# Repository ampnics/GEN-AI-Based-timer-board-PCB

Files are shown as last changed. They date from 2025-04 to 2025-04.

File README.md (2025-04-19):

Gen-AI-Based Timer Board using KiCad and DeepSeek
This project demonstrates the design of a timer control board created using traditional EDA tools supported by generative AI guidance. The goal was to explore how AI can assist in real-world hardware development, from concept to PCB.

Overview
This timer board is designed for applications such as:

Delay-based relay switching

Countdown-based automation

General purpose timing control in embedded systems

It features an ESP-based controller, a relay driver circuit, an OLED display for user feedback, and input buttons for setting time values.

AI Collaboration using DeepSeek
Throughout the project, DeepSeek AI was used to accelerate and refine different stages of the hardware design process:

Block Diagram: AI-generated block-level architecture based on system description.

Schematic Design: Assisted in part selection, logic validation, and drawing guidance.

Design Review: Suggested improvements for schematic correctness and layout optimization.

PCB Layout: Provided tips for routing, placement, EMI handling, and power distribution.

Design Feedback: Rated final design and recommended minor refinements.

Tools Used
KiCad 7.x for schematic and PCB design

DeepSeek AI for design assistance and review

ESP-based microcontroller

Relay module and driver circuitry

OLED I2C display

Tactile push buttons

Repository Structure
/kicad_project: Contains KiCad schematic and PCB layout files

/gerbers: Fabrication-ready Gerber files

/images: Block diagram, schematic snapshots, and board render

/docs: Design notes, AI feedback logs, and changelog

How to Use
Clone the repository

Open the KiCad project from the kicad_project folder

Review or modify the schematic as needed

Generate or inspect Gerber files for fabrication

Refer to the /docs folder for design rationale and review feedback

License
This project is open-sourced under the MIT License. You are free to use, modify, and distribute it for personal or commercial use.

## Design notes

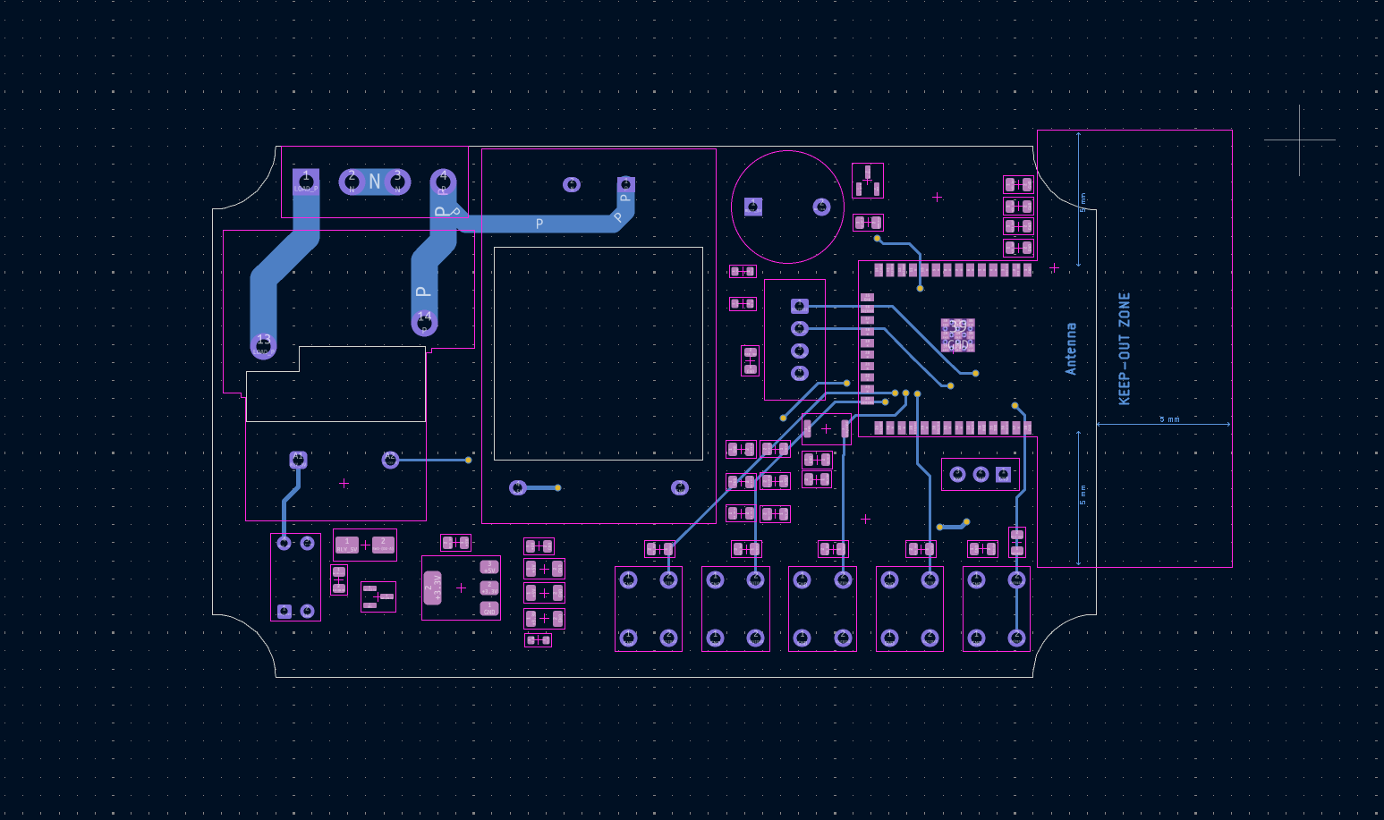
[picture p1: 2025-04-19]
MHDK_03/images/B.Cu_layer.png

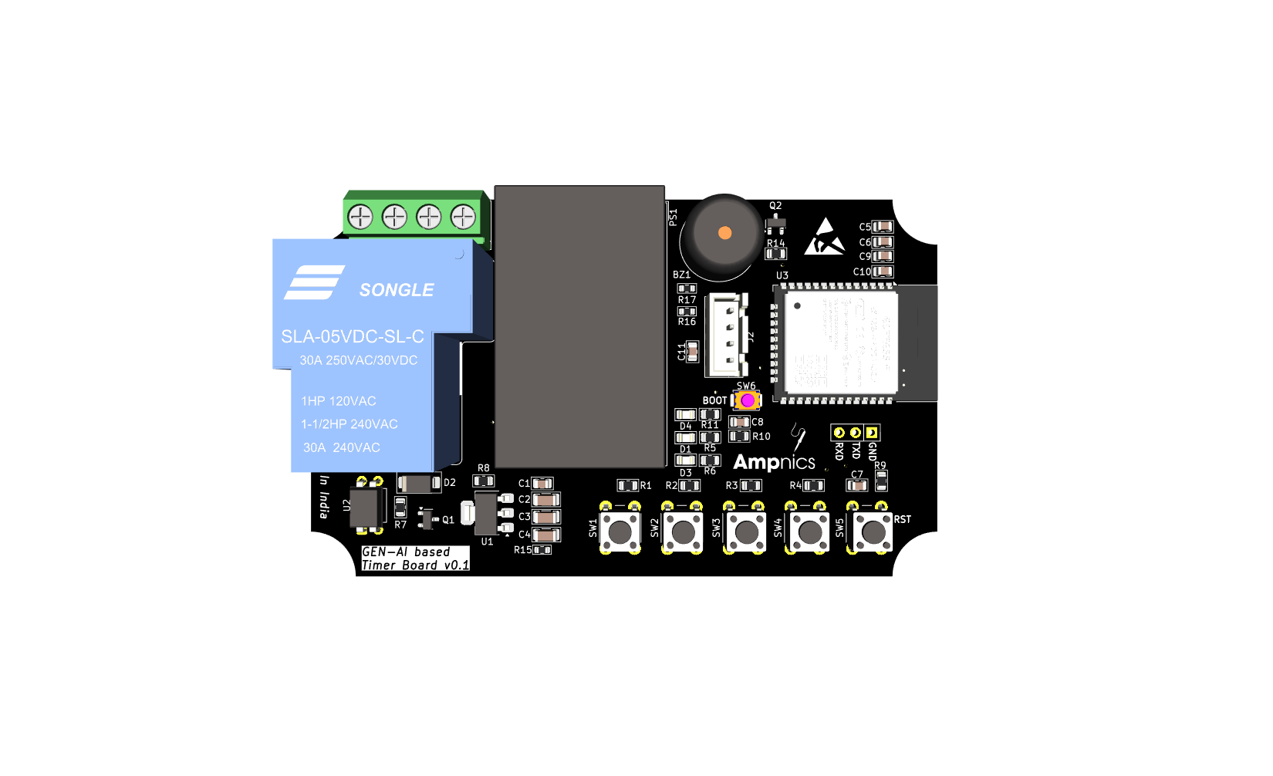
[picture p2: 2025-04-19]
MHDK_03/images/Top.png

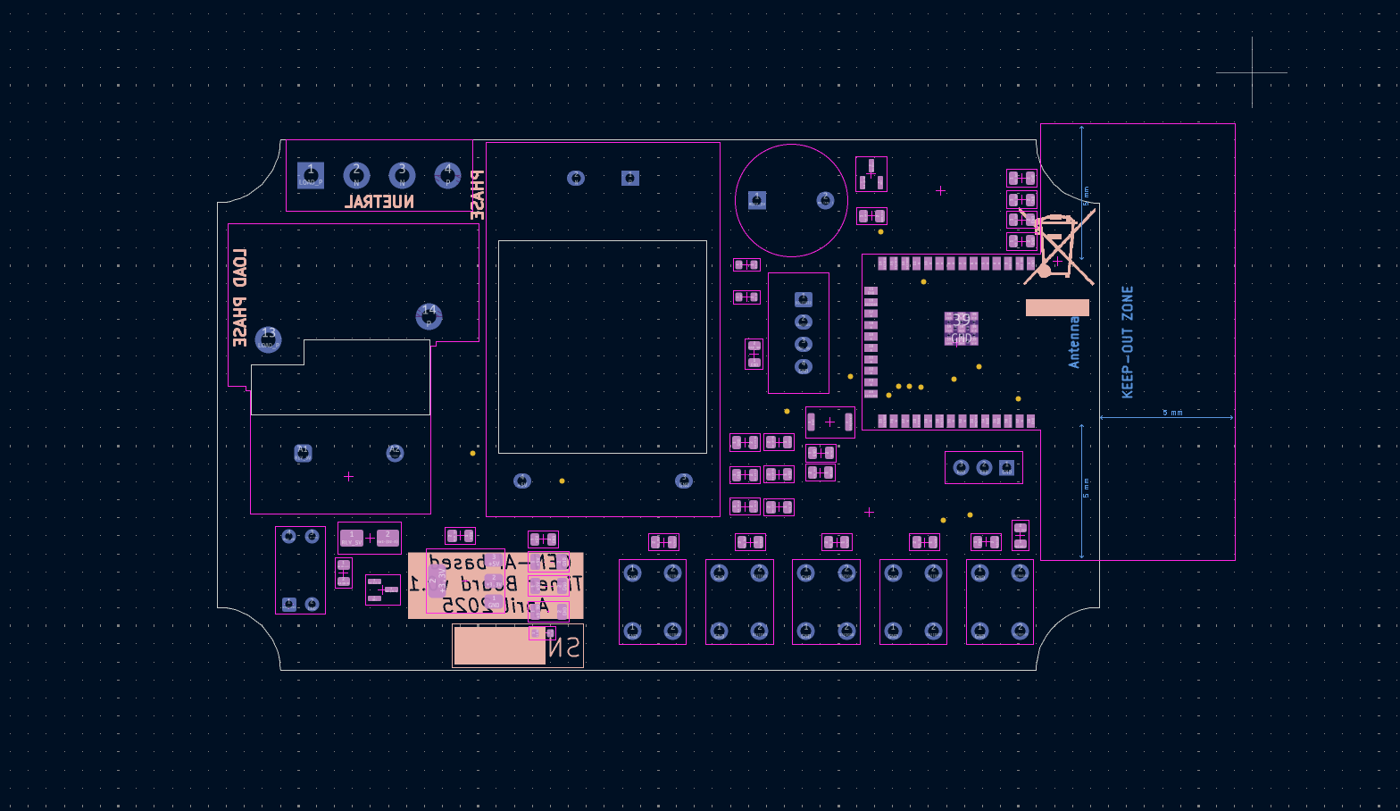
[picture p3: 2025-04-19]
MHDK_03/images/B.Slikscreen.png

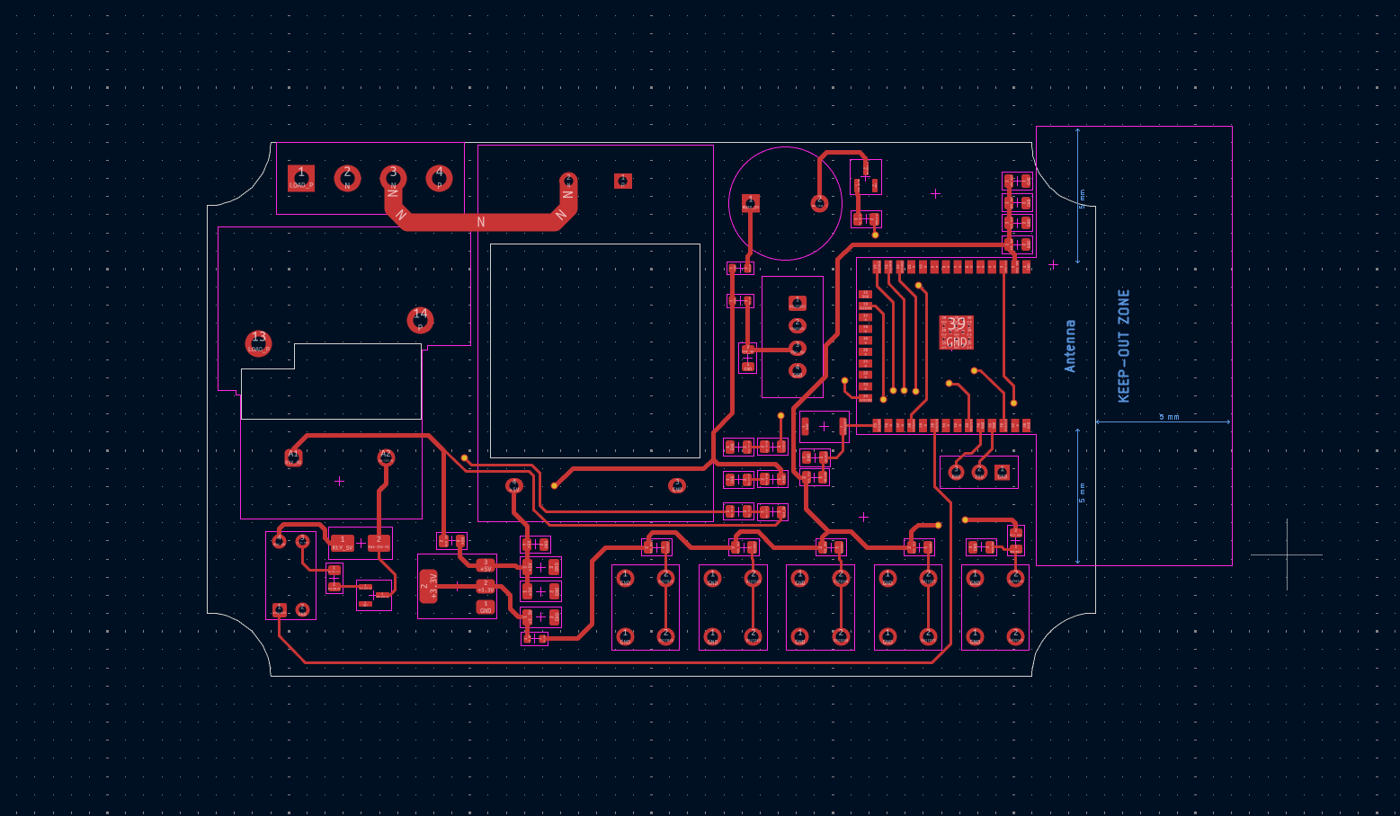
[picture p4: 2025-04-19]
MHDK_03/images/F.Cu_layer.png

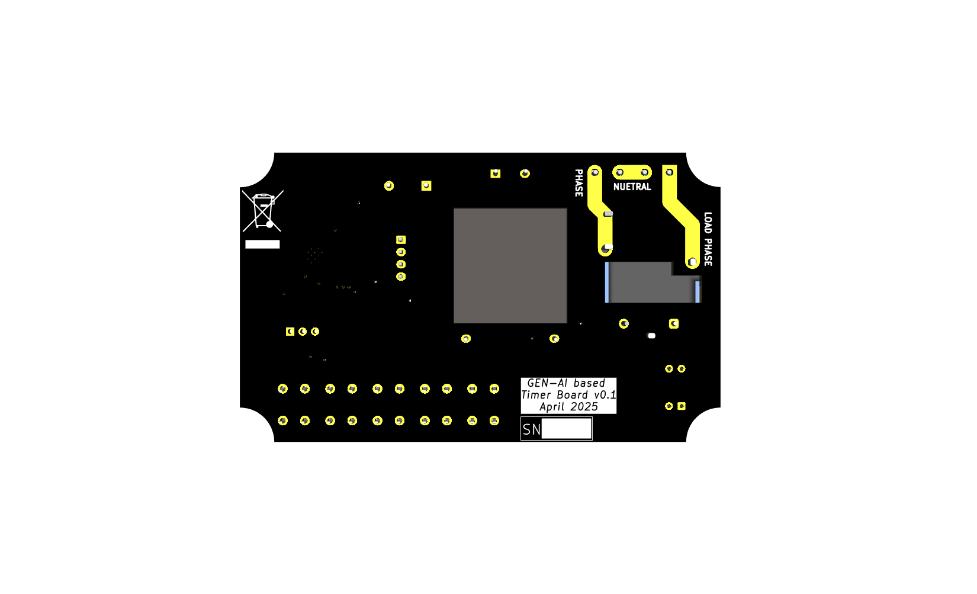
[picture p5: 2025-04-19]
MHDK_03/images/Bottom.png

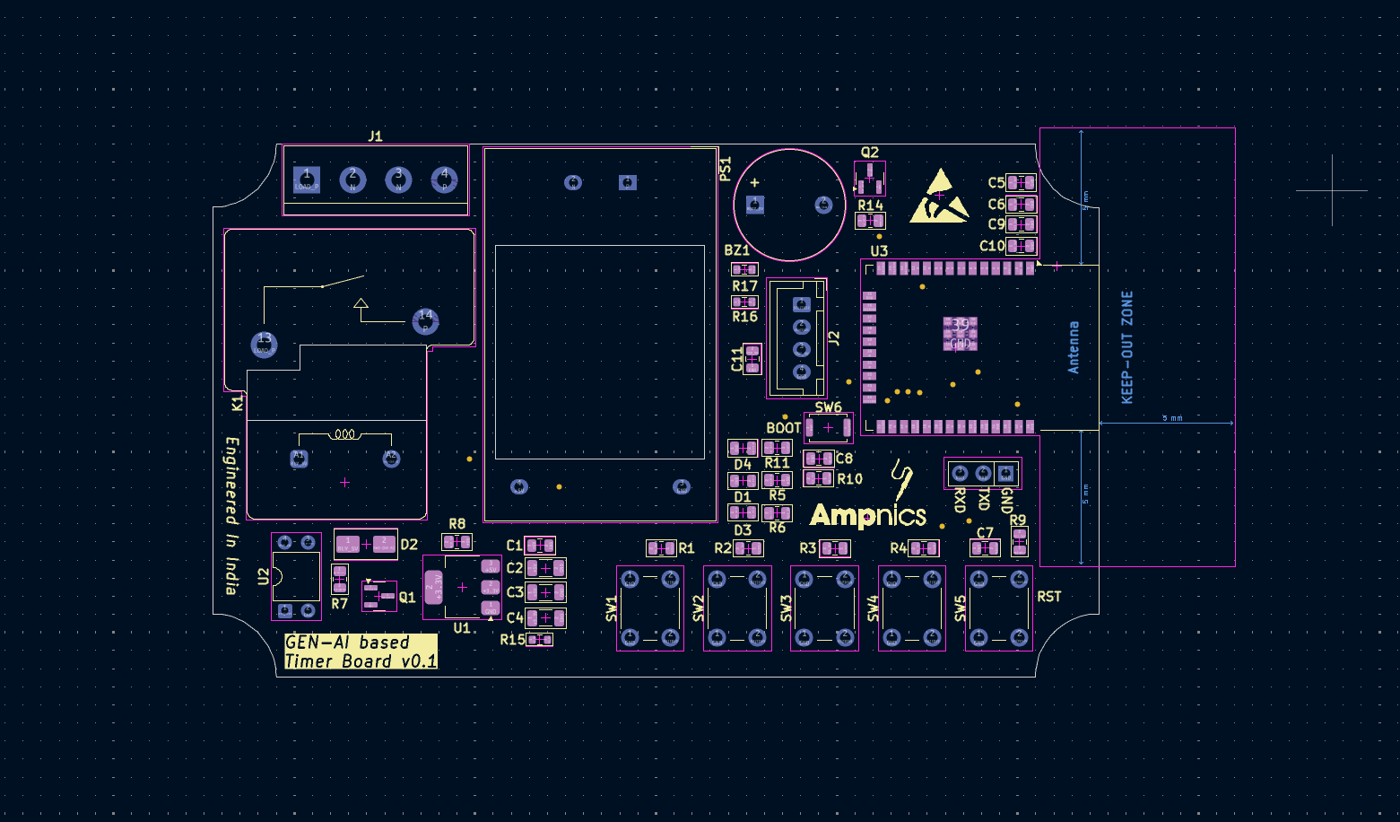
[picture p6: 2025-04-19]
MHDK_03/images/F.Slikscreen.png

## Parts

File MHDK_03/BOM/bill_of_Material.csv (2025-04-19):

Reference | Qty | Value | DNP | Exclude from BOM | Exclude from Board | Footprint | Datasheet
BZ1 | 1 | Buzzer |  |  |  | Buzzer_Beeper:Buzzer_12x9.5RM7.6 | ~
C1,C5,C6,C7,C8,C9,C10,C11 | 8 | 0.1uF |  |  |  | Capacitor_SMD:C_0805_2012Metric | ~
C2 | 1 | 10uF/25V |  |  |  | Capacitor_SMD:C_1206_3216Metric | ~
C3,C4 | 2 | 10uF |  |  |  | Capacitor_SMD:C_1206_3216Metric | ~
D1,D3,D4 | 3 | LED |  |  |  | LED_SMD:LED_0805_2012Metric | ~
D2 | 1 | SS24 |  |  |  | Diode_SMD:D_SMA | https://www.vishay.com/docs/88748/ss22.pdf
J1 | 1 | Screw_Terminal_01x04 |  |  |  | TerminalBlock:TerminalBlock_bornier-4_P5.08mm | ~
J2 | 1 | Conn_01x04_Pin |  |  |  | Connector_JST:JST_XH_B4B-XH-A_1x04_P2.50mm_Vertical | ~
J3 | 1 | Conn_01x03_Pin |  |  |  | Connector_PinSocket_2.54mm:PinSocket_1x03_P2.54mm_Vertical | ~
K1 | 1 | RAYEX-L90AS |  |  |  | Relay_THT:Relay_SPST_RAYEX-L90AS | https://a3.sofastcdn.com/attachment/7jioKBjnRiiSrjrjknRiwS77gwbf3zmp/L90-SERIES.pdf
PS1 | 1 | HLK-5M05 |  |  |  | Converter_ACDC:Converter_ACDC_Hi-Link_HLK-5Mxx | http://h.hlktech.com/download/ACDC%E7%94%B5%E6%BA%90%E6%A8%A1%E5%9D%975W%E7%B3%BB%E5%88%97/1/%E6%B5%B7%E5%87%8C%E7%A7%915W%E7%B3%BB%E5%88%97%E7%94%B5%E6%BA%90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
Q1,Q2 | 2 | MMBT2222A |  |  |  | Package_TO_SOT_SMD:SOT-23 | https://assets.nexperia.com/documents/data-sheet/MMBT2222A.pdf
R1,R2,R3,R4,R9,R10 | 6 | 10K |  |  |  | Resistor_SMD:R_0805_2012Metric | ~
R5 | 1 | 2K2 |  |  |  | Resistor_SMD:R_0805_2012Metric | ~
R6,R7 | 2 | 1k |  |  |  | Resistor_SMD:R_0805_2012Metric | ~
R8 | 1 | 0R |  |  |  | Resistor_SMD:R_0805_2012Metric | ~
R11 | 1 | 1K |  |  |  | Resistor_SMD:R_0805_2012Metric | ~
R14 | 1 | 330R |  |  |  | Resistor_SMD:R_0805_2012Metric | ~
R15,R16,R17 | 3 | 0R |  |  |  | Resistor_SMD:R_0603_1608Metric | ~
SW1,SW2,SW3,SW4,SW5 | 5 | SW_Push |  |  |  | Button_Switch_THT:SW_PUSH_6mm | ~
SW6 | 1 | SW_Push |  |  |  | Button_Switch_SMD:SW_Push_SPST_NO_Alps_SKRK | ~
U1 | 1 | AMS1117-3.3 |  |  |  | Package_TO_SOT_SMD:SOT-223-3_TabPin2 | http://www.advanced-monolithic.com/pdf/ds1117.pdf
U2 | 1 | PC817 |  |  |  | Package_DIP:DIP-4_W7.62mm | http://www.soselectronic.cz/a_info/resource/d/pc817.pdf
U3 | 1 | ESP32-WROOM-32D |  |  |  | RF_Module:ESP32-WROOM-32D | https://www.espressif.com/sites/default/files/documentation/esp32-wroom-32d_esp32-wroom-32u_datasheet_en.pdf

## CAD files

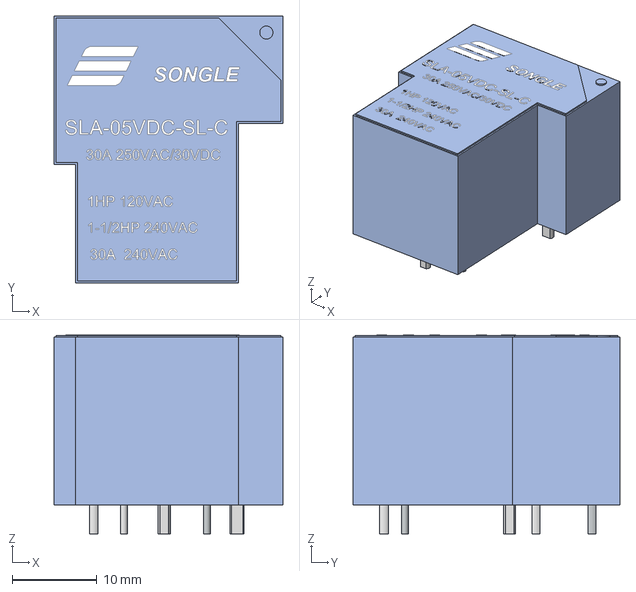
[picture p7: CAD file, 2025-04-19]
MHDK_03/external 3d models/Relay - SLA-05VDC-SL-C.stp
27.1 x 31.6 x 23.5 mm

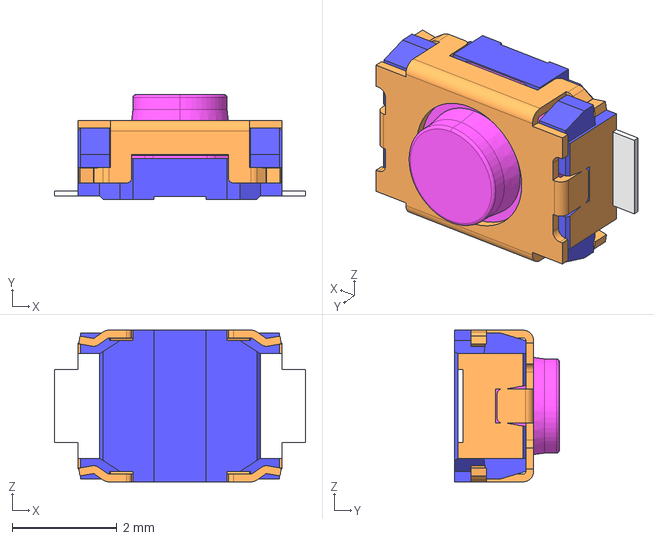
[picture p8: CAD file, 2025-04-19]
MHDK_03/external 3d models/skrkaee010.stp
4.80 x 2.00 x 2.90 mm

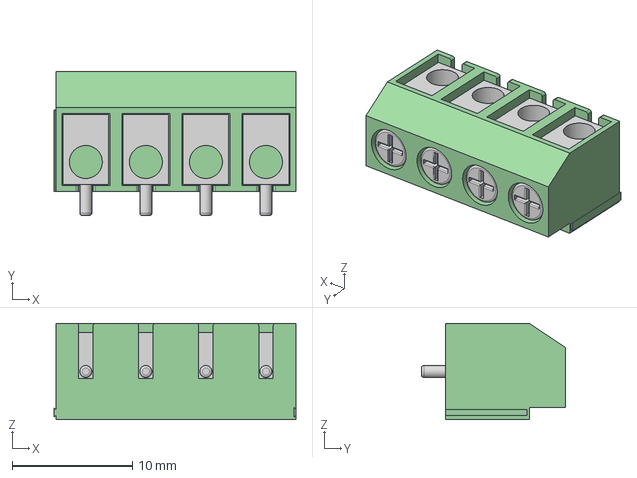
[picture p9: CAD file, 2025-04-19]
MHDK_03/external 3d models/Screw Terminal Block 5mm 4-way.step
20.1 x 12.0 x 8.00 mm

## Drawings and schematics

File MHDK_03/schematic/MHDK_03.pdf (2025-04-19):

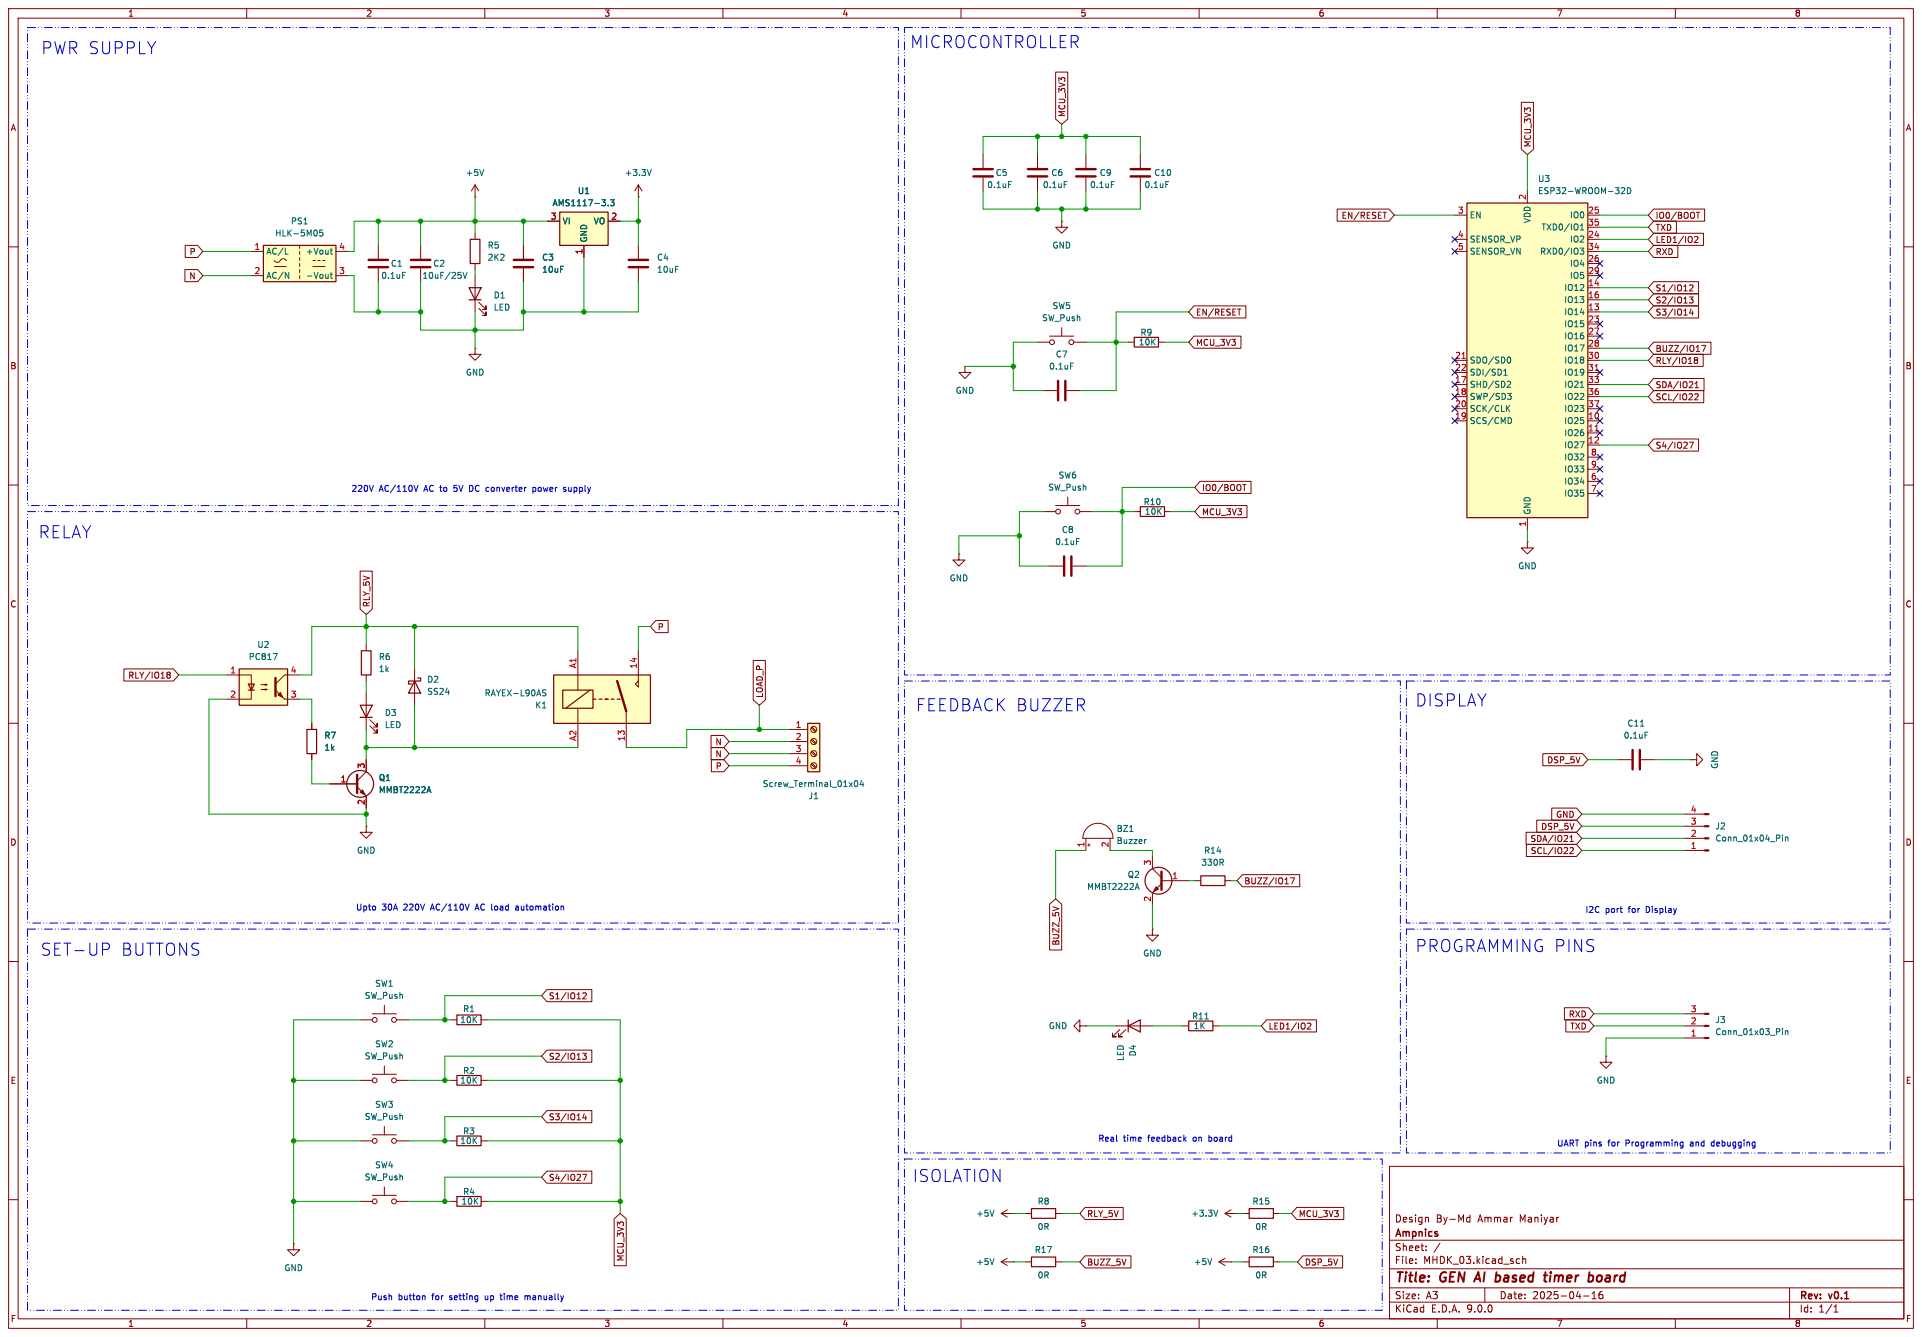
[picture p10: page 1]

IO0/BOOT EN/RESET RELAY

Real time feedback on board

Id: 1/1 Title: GEN AI based timer board

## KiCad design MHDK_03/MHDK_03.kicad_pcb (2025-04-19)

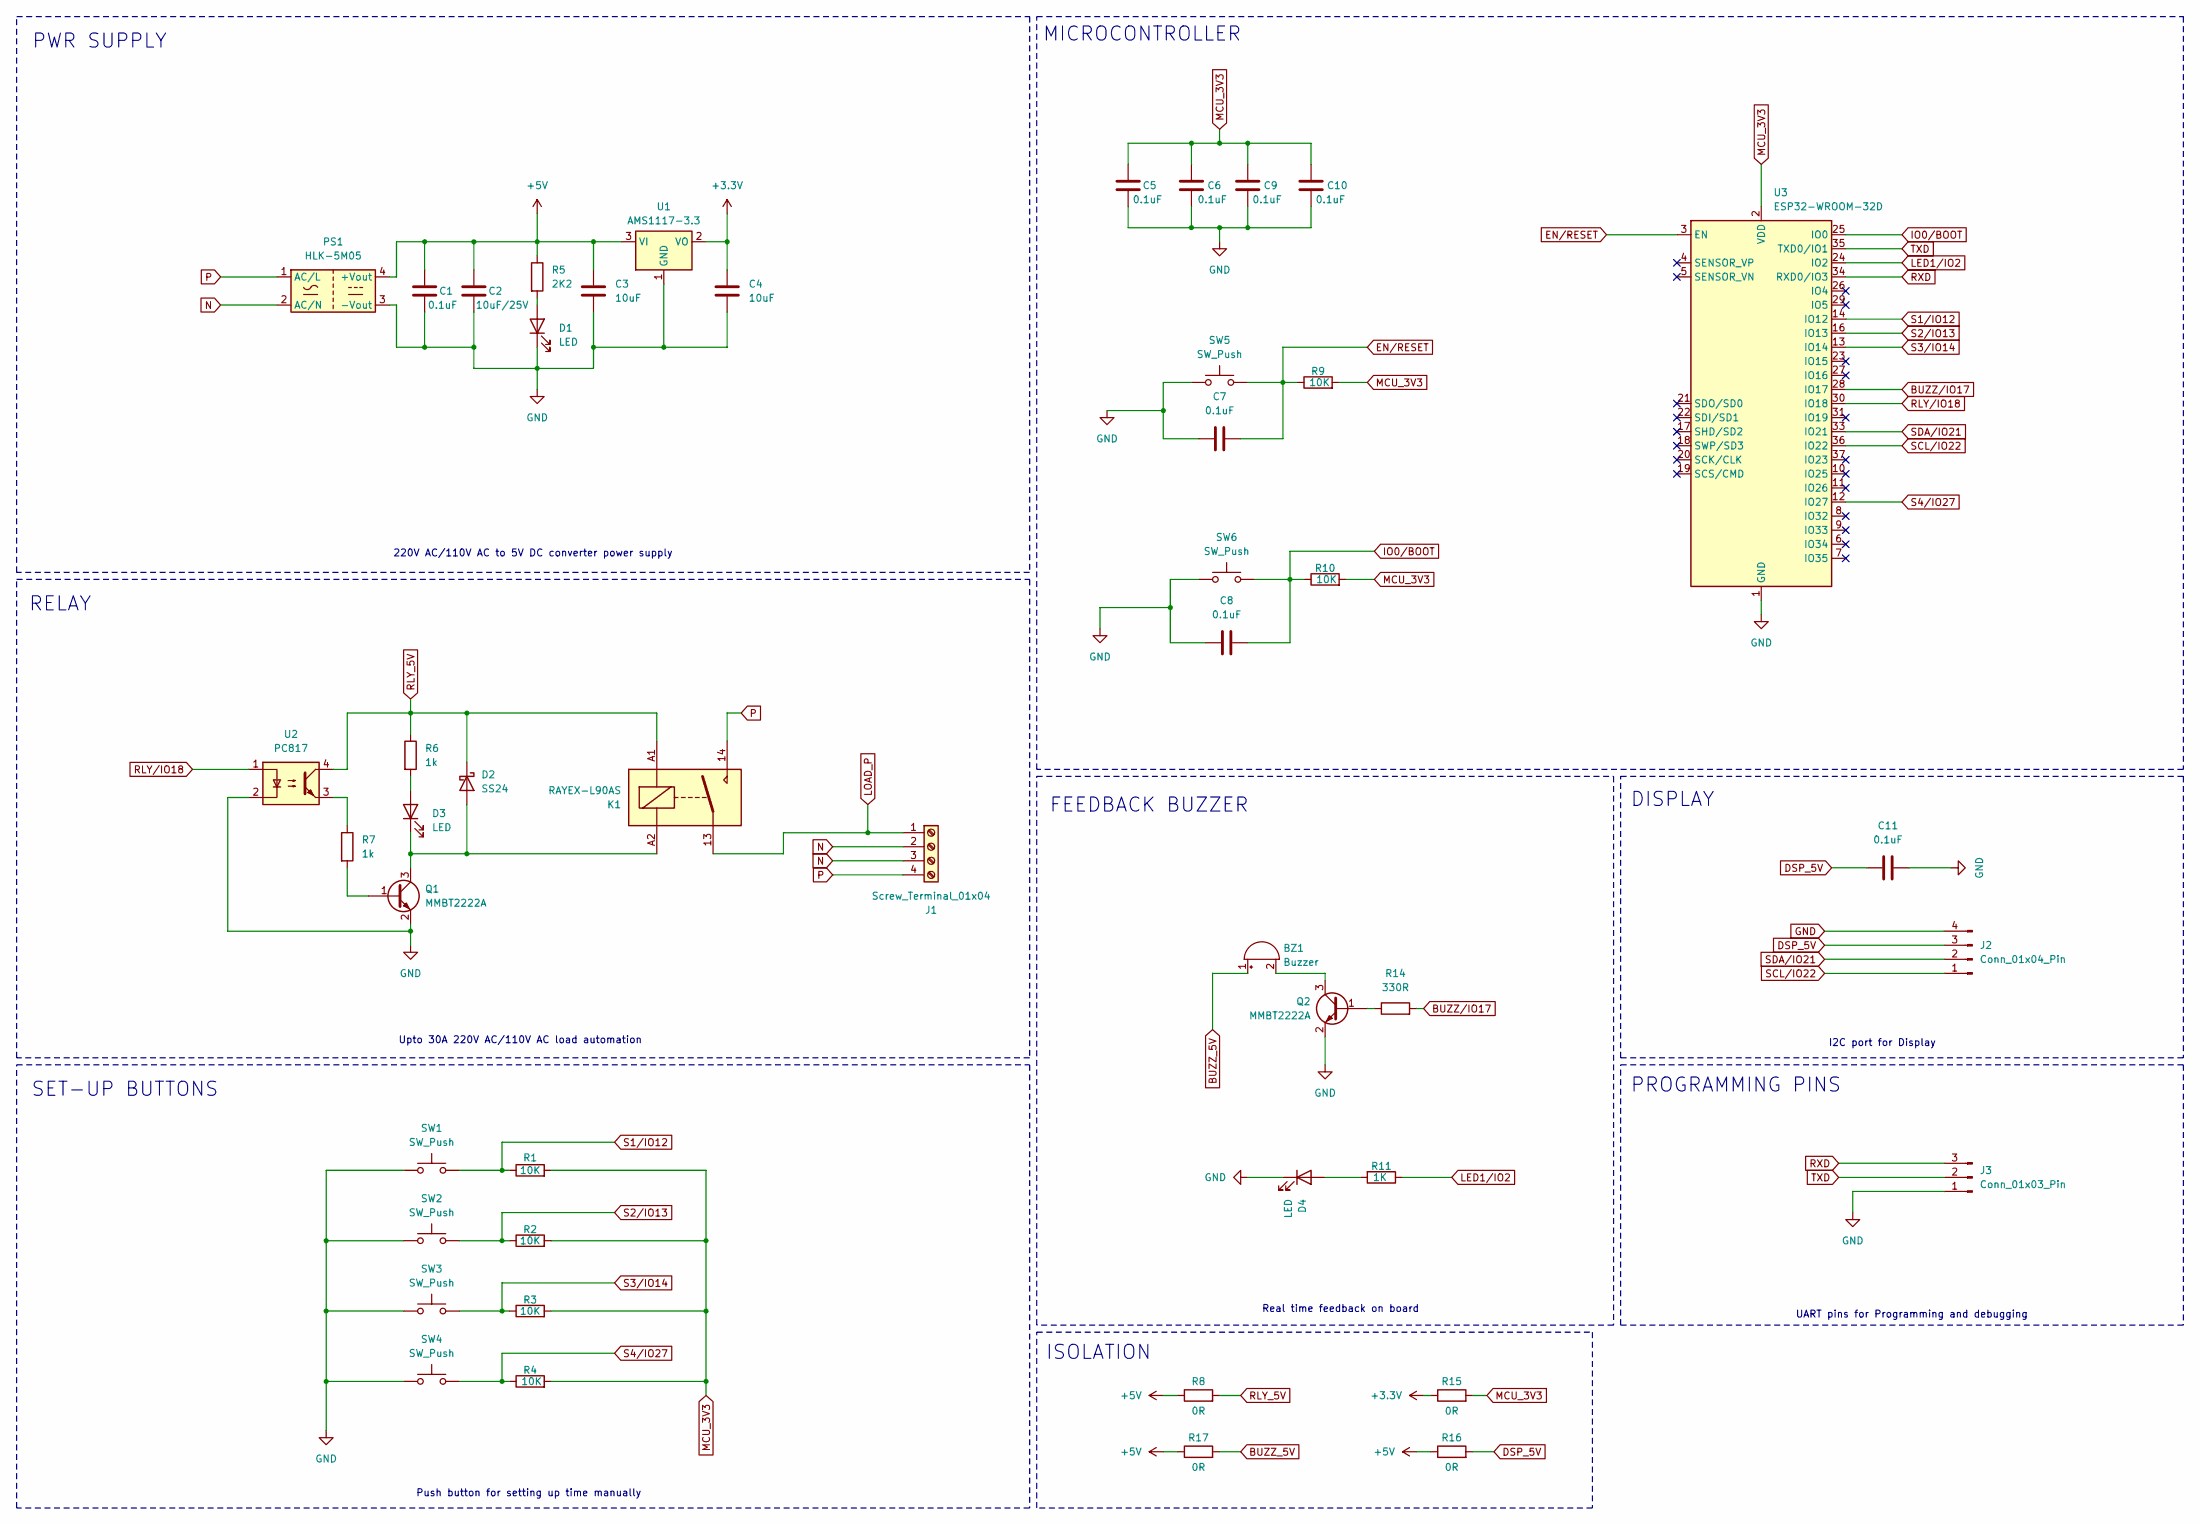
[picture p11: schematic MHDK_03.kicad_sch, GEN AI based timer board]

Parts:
BZ1: Buzzer; Buzzer_12x9.5RM7.6
C1, C5, C6, C7, C8, C9, C10, C11: 0.1uF; C_0805_2012Metric
C2: 10uF/25V; C_1206_3216Metric
C3, C4: 10uF; C_1206_3216Metric
D1, D3, D4: LED; LED_0805_2012Metric
D2: SS24; D_SMA
J1: Screw_Terminal_01x04; TerminalBlock_bornier-4_P5.08mm
J2: Conn_01x04_Pin; JST_XH_B4B-XH-A_1x04_P2.50mm_Vertical
J3: Conn_01x03_Pin; PinSocket_1x03_P2.54mm_Vertical
K1: RAYEX-L90AS; Relay_SPST_RAYEX-L90AS
PS1: HLK-5M05; Converter_ACDC_Hi-Link_HLK-5Mxx
Q1, Q2: MMBT2222A; SOT-23
R1, R2, R3, R4, R9, R10: 10K; R_0805_2012Metric
R5: 2K2; R_0805_2012Metric
R6, R7: 1k; R_0805_2012Metric
R8: 0R; R_0805_2012Metric
R11: 1K; R_0805_2012Metric
R14: 330R; R_0805_2012Metric
R15, R16, R17: 0R; R_0603_1608Metric
SW1, SW2, SW3, SW4, SW5: SW_Push; SW_PUSH_6mm
SW6: SW_Push; SW_Push_SPST_NO_Alps_SKRK
U1: AMS1117-3.3; SOT-223-3_TabPin2
U2: PC817; DIP-4_W7.62mm
U3: ESP32-WROOM-32D

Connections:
+3.3V: C4.1, R15.1, U1.2 (VO)
+5V: C1.1, C2.1, C3.1, PS1.4 (+Vout), R5.1, R8.1, R16.1, R17.1, U1.3 (VI)
BUZZ_5V: BZ1.1 (+), R17.2
BUZZ/IO17: R14.2, U3.28 (IO17)
DSP_5V: C11.2, J2.3, R16.2
EN/RESET: C7.2, R9.1, SW5.2, U3.3 (EN)
GND: C1.2, C2.2, C3.2, C4.2, C5.2, C6.2, C7.1, C8.1, C9.2, C10.2, C11.1, D1.1 (K), D4.1 (K), J2.4, J3.1, PS1.3 (-Vout), Q1.2 (E), Q2.2 (E), SW1.1, SW2.1, SW3.1, SW4.1, SW5.1, SW6.1, U1.1 (GND), U2.2, U3.1 (GND), U3.15 (GND), U3.38 (GND), U3.39 (GND)
IO0/BOOT: C8.2, R10.1, SW6.2, U3.25 (IO0)
LED1/IO2: R11.1, U3.24 (IO2)
LOAD_P: J1.1, K1.13
MCU_3V3: C5.1, C6.1, C9.1, C10.1, R1.2, R2.2, R3.2, R4.2, R9.2, R10.2, R15.2, U3.2 (VDD)
N: J1.2, J1.3, PS1.2 (AC/N)
unnamed: BZ1.2 (-), Q2.3 (C)
unnamed: D1.2 (A), R5.2
unnamed: D2.2 (A), D3.1 (K), K1.A2, Q1.3 (C)
unnamed: D3.2 (A), R6.2
unnamed: D4.2 (A), R11.2
unnamed: Q1.1 (B), R7.2
unnamed: Q2.1 (B), R14.1
unnamed: R7.1, U2.3
P: J1.4, K1.14, PS1.1 (AC/L)
RLY_5V: D2.1 (K), K1.A1, R6.1, R8.2, U2.4
RLY/IO18: U2.1, U3.30 (IO18)
RXD: J3.3, U3.34 (RXD0/IO3)
S1/IO12: R1.1, SW1.2, U3.14 (IO12)
S2/IO13: R2.1, SW2.2, U3.16 (IO13)
S3/IO14: R3.1, SW3.2, U3.13 (IO14)
S4/IO27: R4.1, SW4.2, U3.12 (IO27)
SCL/IO22: J2.1, U3.36 (IO22)
SDA/IO21: J2.2, U3.33 (IO21)
TXD: J3.2, U3.35 (TXD0/IO1)

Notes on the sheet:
Push button for setting up time manually
Real time feedback on board
RELAY
SET-UP BUTTONS
Upto 30A 220V AC/110V AC load automation
PROGRAMMING PINS
I2C port for Display
MICROCONTROLLER
PWR SUPPLY
ISOLATION
DISPLAY
220V AC/110V AC to 5V DC converter power supply
UART pins for Programming and debugging
FEEDBACK BUZZER

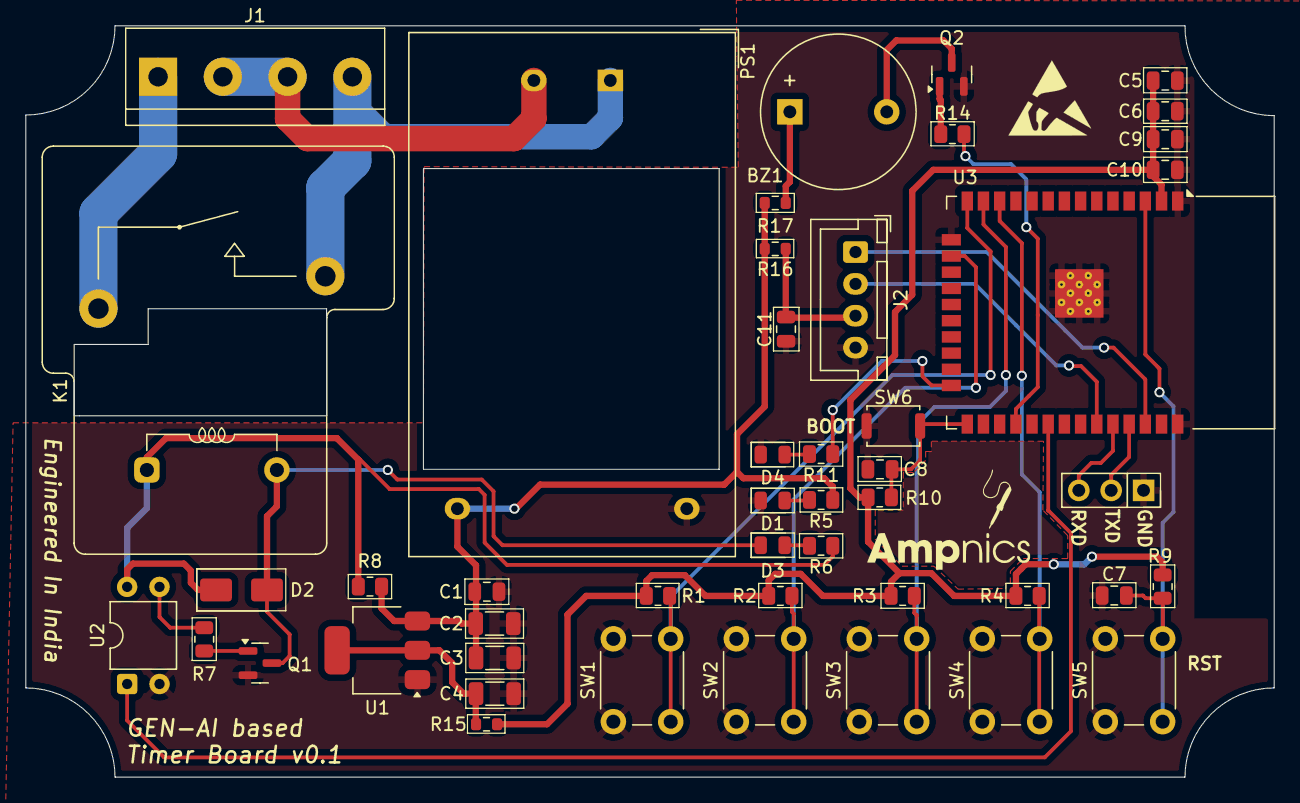
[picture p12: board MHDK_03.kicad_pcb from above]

Board: 2 copper layers, 97.9 x 58.9 mm, 47 parts (0 on the bottom side), 31 nets.
